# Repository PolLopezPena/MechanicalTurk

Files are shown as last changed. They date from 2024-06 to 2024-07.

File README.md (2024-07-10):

# Mechanical-Turk

## Table of Contents
- [What is it?](#What-is-it?)
- [Requirements](#Requirements)
- [Documentation](#Documentation)
- [Install](#Install)
- [Hardware](#Hardware)
  - [Chess](#Chess)
  - [Face](#Face)
- [Schematic](#Schematic)
- [Software](#Software)
- [3D Components](#3D-Components)
  - [Components List](#Components-List)
  - [How to Use the 3D Files](#How-to-Use-the-3D-Files)
  - [Folder Structure](#Folder-Structure)
- [Authors](#Authors)

## What is it?
The project involves creating an automated chess system inspired by the legendary "Mechanical Turk". This system allows a human user to play chess against a machine, which not only calculates and executes moves on the board but also interacts emotionally through a robotic face. The objective of the project is to combine advanced computer vision, robotics, and programming techniques to offer a unique and interactive gameplay experience.

[Video Chess](https://youtu.be/1_45zRi992Q)

[Video Face](https://www.youtube.com/shorts/0_kBC2aJgIs?feature=share)

## Requirements
**Chess**

 - pip install chess
 
 - pip install stockfish
 
 - pip install time
 
 - pip install RPi.GPIO

 **Face**
 
 - Wire

 - Adafruit_PWMServoDriver

 - SoftwareSerial

 - Adafruit_GFX

 - Adafruit_NeoMatrix

## Documentation

**Project Components**

The project consists of several key components that work together to create a cohesive and smooth experience:

**1. Interactive Chessboard**

*  **Board**: A standard chessboard with magnetic pieces.

*  **Camera**: A camera mounted above the board or into the robotic face to capture images and detect piece movements.

**2. Computer Vision System** 

*  **Piece Detection**: Uses computer vision techniques to recognize and track the pieces on the board.

*  **Movement Recognition**: Detects and records the user's moves by comparing the current state of the board with a reference image.

**3. Piece Movement Mechanism**

*  **Axis System**: X-Y axes equipped with stepper motors that control an electromagnet to move the pieces on the board.

*  **Electromagnet**: Placed under the board, this device lifts and moves the pieces to the desired position.

**4. Chess Control Software**

*  **Chess Engine**: Uses Stockfish, one of the most advanced chess engines, to calculate the machine's moves.

*  **Control Interface**: A Python program that coordinates communication between the chess engine, the vision system, and the motor controller.

**5. Interactive Robotic Face**

*  **Eyes, Brows and Mouth**: Displays different facial expressions in response to the state of the game.

*  **Gestures and Expressions**: Programmed gestures and facial expressions to reflect emotions like happiness, surprise, or frustration, depending on the game's progress.

## Install
To set up Mechanical Turk, follow these steps:

1. Clone the repository to your local machine. $git clone https://github.com/PolLopezPena/MechanicalTurk.git
2. Install the required libraries (check requirements).
3. Execute main Python script.

## Hardware
- ### Chess
| Component | Image | Link |
|---|-----|---|
|**5V stepper motor :**| motor-28byj-48-paso-a-paso-de-5v| https://goo.su/S9cJCD |
|**ULN2003-Stepper Motor Driver Board:**| | https://goo.su/S9cJCD |
|**OcioDual Relay Module 5V 10A:**| 51sQx-WGVOL | https://goo.su/Mz3IfKR |
|**Electromagnet 12V:**|s-l1600 | https://goo.su/75PAyq |
|**Raspberry Pi 3B:**|91zSu44+34L _AC_UF894,1000_QL80_ | https://goo.su/UA1p |
|**Raspberry Pi Camera v2:**|6169R+wUp8L | https://goo.su/2GHD9UQ |
|**ATX 500W Power Supply:**|s-l600 | https://acortar.link/dsBHzn |
|**456 Point Breadboard:**|Breadboard_456P_Vellemans_1-600x600|https://acortar.link/TY06Ol |

- ### Face
| Component | Image | Link |
|---|-----|---|
|**Arduino Nano:**| 73b102980_arduino-nano-r3_x | https://n9.cl/pvt57b|
|**PCA9685 Controller:**| 51kshHMO+YL _AC_ | https://acortar.link/6Guztp
|**4x Micro servo 9G:**| 61uoCSp26qL | https://n9.cl/h44zv|
|**Arduino Uno:**|  | https://n9.cl/hab0d|
|**Neopixel Neomatrix 8x32** | PPADA2294_Neopixel_RGB_LED_MATRIX_FLEXIBLE_main3__44844|https://acortar.link/TBNjKt|

## Schematic
- ### Chess
Chess_sketch
- ### Face
Cabeza_sketch

## Software
### Computer Vision Software
On /Computer_Vision there is the file used to detect the different pieces and the board. The code detects the chessboard and the type of the pieces (Green or Red ones), marking each with a different colour. From the detection, the code also returns the coordinates of where each piece is.

This section lists the 3D components used in the project along with their descriptions, dimensions, and links to the corresponding 3D files.

**IMPORTANT:** In order to use the code you must download [yolov5](https://github.com/ultralytics/yolov5) and place it in a /models sub repository inside the projects repository and place the images desired to be detected inside a /image repository. As seen in lines 111 and 113 in the code.



### Face Software
softwarecara

### Chess Software
ChessSoftware

## 3D Components
### Components List
**1. Rail (2 pieces)**

*  **Description**: Rails for moving the X-Y axes.
*  **Dimensions**:
     * Length: 39.5 cm
       
     * Width: 4 cm
       
     * Height: 3 cm
       
*  **File**: rail.stl

**2. Small Support (2 pieces)**

*  **Description**: First support for mounting one rail on top of another; second support for mounting the electromagnet on the upper rail.
*  **Dimensions**:
     *  Length: 6 cm

     *  Width: 5 cm

     *  Height: 3.65 cm
       
*  **File**: small_support.stl

**3. Wheel Support (2 pieces)**

*  **Description**: Provides stability to the upper rail to prevent oscillation during movement.
*  **Dimensions**:
     *  Length: 1.4 cm
       
     *  Width: 4.2 cm
       
     *  Height: 3.5 cm
       
*  **File**: wheel_support.stl

**4. Motor Support (2 pieces)**

*  **Description**: Holds the motor that drives the belt.
*  **Dimensions**:
     *  Length: 6.5 cm
       
     *  Width: 5 cm
       
     *  Height: 2 cm
       
*  **File**: motor_support.stl

**5. Belt Support (2 pieces)**

*  **Description**: Provides extra support for the belt at the end of the rail.
*  **Dimensions**:
     *  Length: 4 cm
       
     *  Width: 5 cm
       
     *  Height: 2 cm
       
*  **File**: belt_support.stl

**6. Chessboard**

*  **Description**: The chessboard where the game is played.
*  **Dimensions**:
     *  Length: 47.5 cm
       
     *  Width: 47.5 cm
       
     *  Height: 10 cm
       
*  **File**: chessboard.stl

### How to Use the 3D Files
*  **Download**: Click on the file names above to download the STL files.
*  **Print**: Use a 3D printer to print the components. Ensure that your printer settings match the requirements of each component.

### Folder Structure
*  **3D Files Folder**: All 3D files are stored in the **`/3D_files`** directory of this repository.
* **`/3D_files`**
    *  **`rail.stl`**
      
    *  **`small_support.stl`**
      
    *  **`wheel_support.stl`**
      
    *  **`motor_support.stl`**
      
    *  **`belt_support.stl`**
      
    *  **`chessboard.stl`**

## Authors
* Pol López Peña
* Jhonatan Alejandro Quisbert Tarqui
* Pol González Casals

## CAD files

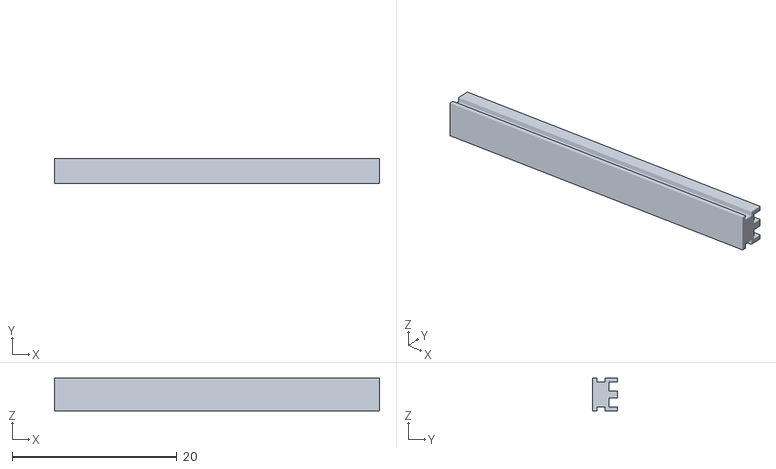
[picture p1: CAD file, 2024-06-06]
3D_files/rail.stl
39.5 x 3.00 x 4.00

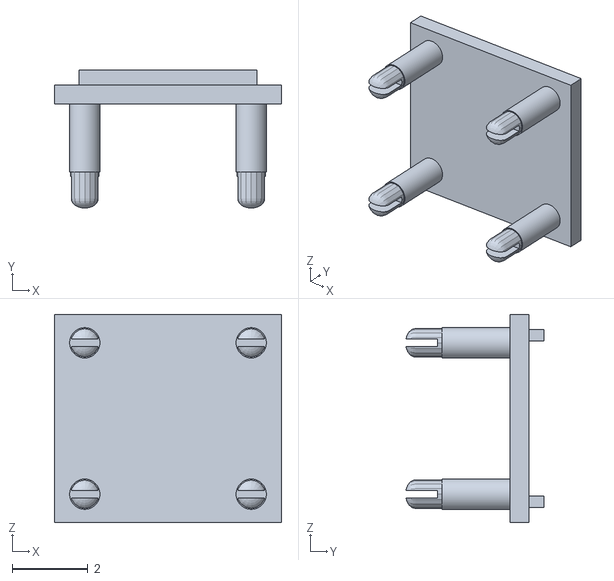
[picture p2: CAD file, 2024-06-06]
3D_files/small_support.stl
6.00 x 3.65 x 5.50

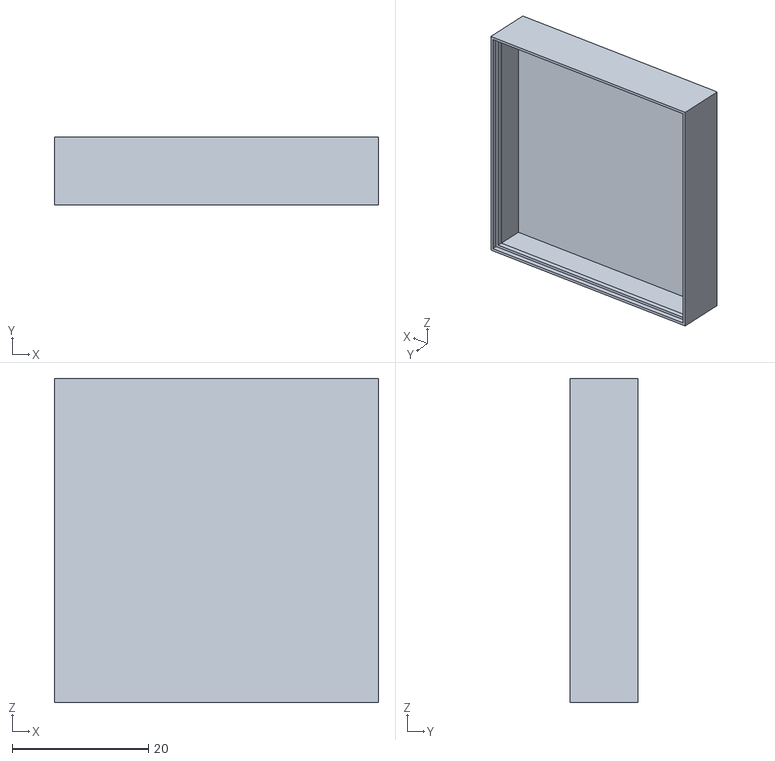
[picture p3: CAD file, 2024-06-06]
3D_files/chessboard.stl
47.5 x 10.0 x 47.5

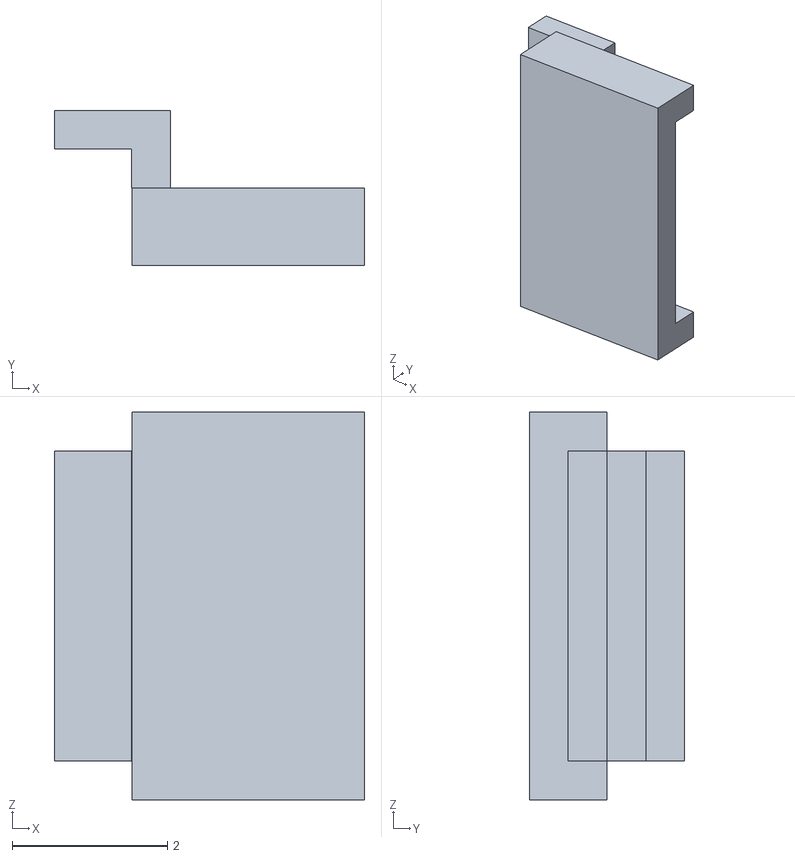
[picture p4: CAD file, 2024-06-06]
3D_files/belt_support.stl
4.00 x 2.00 x 5.00

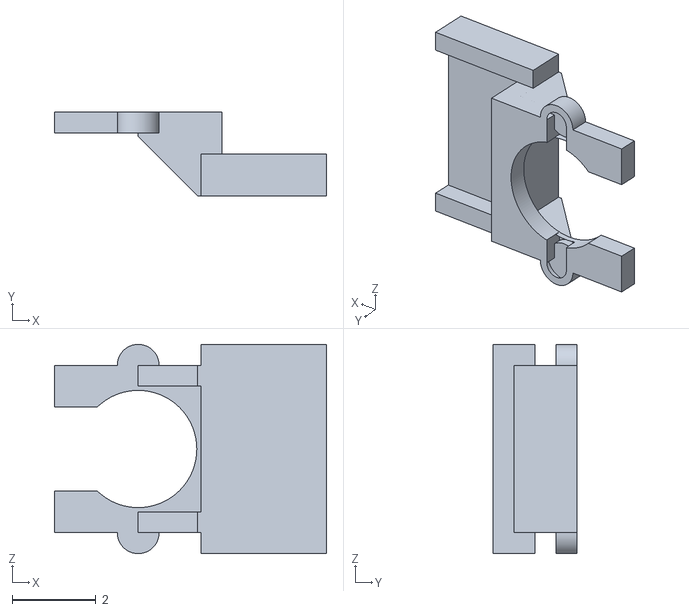
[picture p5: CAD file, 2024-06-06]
3D_files/motor_support.stl
6.50 x 2.00 x 5.00

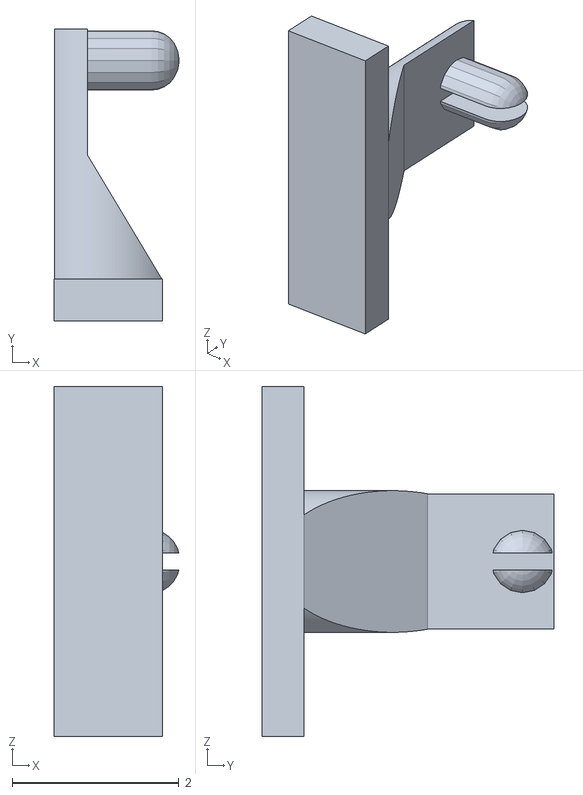
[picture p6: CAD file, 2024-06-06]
3D_files/wheel_support.stl
1.50 x 3.50 x 4.20

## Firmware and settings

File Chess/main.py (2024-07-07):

# This is a sample Python script.
import chess
from stockfish import  Stockfish
import time
import RPi.GPIO as GPIO
# Press Mayús+F10 to execute it or replace it with your code.
# Press Double Shift to search everywhere for classes, files, tool windows, actions, and settings.

# Press the green button in the gutter to run the script.

def init():
        GPIO.setmode(GPIO.BCM)
        magnet = 21
        StepPins = [24, 25, 8, 7]
        StepPins2 = [17, 18, 27, 22]
        for pin in StepPins2:
                print("SetUp Pins1")
                GPIO.setup(pin, GPIO.OUT)
                GPIO.output(pin, False)
        for pin in StepPins:
                print("SetUp Pins2")
                GPIO.setup(pin, GPIO.OUT)
                GPIO.output(pin, False)
        GPIO.setup(magnet, GPIO.OUT)
        return StepPins, StepPins2, magnet
def moveToCoordinate(movement):
        mapping = {'a':1, 'b':2, 'c':3, 'd':4, 'e':5, 'f':6, 'g':7, 'h':8}
        row = mapping[movement[0]]
        col = int(movement[1])
        return row, col
waitTime = 0.002
#Normal-step
# Define simple sequence
StepCount1 = 4
Seq1 = []
Seq1 = [i for i in range(0, StepCount1)]
Seq1[0] = [1, 0, 0, 0]
Seq1[1] = [0, 1, 0, 0]
Seq1[2] = [0, 0, 1, 0]
Seq1[3] = [0, 0, 0, 1]
# Define advanced half-step sequence
StepCount2 = 8
Seq2 = []
Seq2 = [i for i in range(0, StepCount2)]
Seq2[0] = [1, 0, 0, 0]
Seq2[1] = [1, 1, 0, 0]
Seq2[2] = [0, 1, 0, 0]
Seq2[3] = [0, 1, 1, 0]
Seq2[4] = [0, 0, 1, 0]
Seq2[5] = [0, 0, 1, 1]
Seq2[6] = [0, 0, 0, 1]
Seq2[7] = [1, 0, 0, 1]

Seq = Seq2
StepCount = StepCount2

x1 = 0
y1 = 0
x2 = 8
y2 = 8

stepsPerSquare = 2200

def steps(number, pins):
    print(pins)
    StepCounter = 0
    if number < 0:
        sign = -1
    else:
        sign = 1
    nb = abs(number)*2  # Half-step
    for i in range(nb):
        for pin in range(4):
            xpin = pins[pin]
            if Seq[StepCounter][pin] != 0:
                GPIO.output(xpin, True)
            else:
                GPIO.output(xpin, False)
        StepCounter += sign

        if StepCounter == StepCount:
            StepCounter = 0
        if StepCounter < 0:
            StepCounter = StepCount - 1
        time.sleep(waitTime)

def moveController(xSteps, ySteps):
        hasRun = False
        while not hasRun:
                steps(-stepsPerSquare*xSteps, StepPins2)
                time.sleep(1)
                steps(stepsPerSquare*ySteps, StepPins)
                time.sleep(1)
                hasRun = True
        print("Stop Motos")
        for pin in StepPins:
                GPIO.output(pin, False)
        for pin in StepPins2:
                GPIO.output(pin, False)

def moveDiagonal(way):
        stepC = 0
        stepCounter1 = 0
        while stepC < int(stepsPerSquare):
                for pin in range(4):
                        xpin1 = StepPins[pin]
                        if Seq[stepCounter1][pin] != 0:
                                GPIO.output(xpin1, True)
                        else:
                                GPIO.output(xpin1, False)
                        xpin2 = StepPins2[pin]
                        if Seq[stepCounter1][pin] != 0:
                                GPIO.output(xpin2, True)
                        else:
                                GPIO.output(xpin2, False)
                stepCounter1 += way
                if StepCounter1 == StepCount:
                        StepCounter = 0
                if StepCounter1 < 0:
                        StepCounter1 = StepCount - 1
                time.sleep(waitTime)
                stepC +=1
        print("Stop Motos")
        for pin in StepPins:
                GPIO.output(pin, False)
        for pin in StepPins2:
                GPIO.output(pin, False)

#Movement Pieces
def bishopMovement(wayX, wayY, xsteps, ysteps):
        stepC = 0
        stepCounterX = 0
        stepCounterY = 0
        while stepC < int(stepsPerSquare*2):
                for pin in range(4):
                        xpin1 = StepPins[pin]
                        if Seq[stepCounterY][pin] != 0:
                                GPIO.output(xpin1, True)
                        else:
                                GPIO.output(xpin1, False)
                        xpin2 = StepPins2[pin]
                        if Seq[stepCounterX][pin] != 0:
                                GPIO.output(xpin2, True)
                        else:
                                GPIO.output(xpin2, False)
                stepCounterX += wayX
                stepCounterY += wayY
                if stepCounterX == StepCount:
                        stepCounterX = 0
                if stepCounterX < 0:
                        stepCounterX = StepCount - 1
                if stepCounterY == StepCount:
                        stepCounterY = 0
                if stepCounterY < 0:
                        stepCounterY = StepCount - 1
                time.sleep(waitTime)
                stepC +=1
                
        print("Stop Motos")
        for pin in StepPins:
                GPIO.output(pin, False)
        for pin in StepPins2:
                GPIO.output(pin, False)
def horseMovement(xsteps, ysteps):
        moveDiagonal(1)
        time.sleep(2)
        moveController(xsteps, ysteps)
        time.sleep(2)
        moveDiagonal(-1)
def rookMovement(xsteps, ysteps):
        hasRun = False
        if xsteps != 0:
               steps1 = xsteps 
        else:
                steps1 = ysteps
        while not hasRun:
                steps(-stepsPerSquare*steps1, StepPins2)
                time.sleep(1)
                hasRun = True
        print("Stop Motos")
        for pin in StepPins:
                GPIO.output(pin, False)
        for pin in StepPins2:
                GPIO.output(pin, False)
def queenMovement(xsteps, ysteps):
        if xsteps == ysteps:
                if xsteps < 0:
                        wayX = -1
                else:
                        wayX = 1
                if ysteps < 0:
                        wayY = -1
                else:
                        wayY = 1
                for step in range(xsteps):
                        bishopMovement(wayX, wayY, xsteps, ysteps)
        else:
                rookMovement(xsteps, ysteps)
def pawnMovement(xsteps, ysteps):
        if xsteps == 0:
                hasRun = False
                while not hasRun:
                        steps(-stepsPerSquare*ysteps, StepPins)
                        time.sleep(1)
                        hasRun = True
                print("Stop Motos")
                for pin in StepPins:
                        GPIO.output(pin, False)
                for pin in StepPins2:
                        GPIO.output(pin, False)
        else:
                if xsteps < 0:
                        wayX = -1
                else:
                        wayX = 1
                if ysteps < 0:
                        wayY = -1
                else:
                        wayY = 1
                bishopMovement(wayX, wayY, xsteps, ysteps)
                
def movementPieces(typeM, xsteps, ysteps):
        if typeM == 'R':
                rookMovement(xsteps, ysteps)
        elif typeM == 'N':
                horseMovement(xsteps, ysteps)                
        elif typeM == 'B':
                if xsteps < 0:
                        wayX = -1
                else:
                        wayX = 1
                if ysteps < 0:
                        wayY = -1
                else:
                        wayY = 1
                for step in range(xsteps):
                        bishopMovement(wayX, wayY, xsteps, ysteps)
        elif typeM == 'Q':
                queenMovement(xsteps, ysteps)
        elif typeM == 'K':
                queenMovement(xsteps, ysteps)
        elif typeM == 'P':
                pawnMovement()
if __name__ == '__main__':
    StepPins,StepPins2, electroIman = init()
    board = chess.Board()
    time.sleep(2)
    while(board.is_checkmate() == False):
        stockfish1 = Stockfish("/home/alexquper/RLP/Robotica/Stockfish-sf_15/src/stockfish")
        stockfish1.set_depth(10)
        stockfish1.set_skill_level(10)
        move1 = input('Enter the posotion of the piece: ')
        move2 = input('Enter the position of the square: ')
        move = move1 + move2
        board.push_san(move)
        print(board)
        stockfish1.set_fen_position(board.fen())
        moveIA2 = stockfish1.get_best_move()
        piece2 = moveIA2[0] + moveIA2[1]
        square2 = moveIA2[2] + moveIA2[3]
        board.push_san(moveIA2)
        print(board)
        print(moveIA2)
        x1, y1 = moveToCoordinate(piece2)
        print(x1,y1)
        xsteps = x1 - x2
        ysteps = y1 - y2
        moveController(xsteps, ysteps)
        time.sleep(2)
        
        x2, y2 = moveToCoordinate(square2)
        xsteps = x2 - x1
        ysteps = y2 - y1
        #ActivarElectroIman
        GPIO.output(electroIman, GPIO.HIGH)
        time.sleep(2)
        typePiece = board.piece_at(chess.parse_square(square2))
        print(typePiece)
        movementPieces(typePiece, xsteps, ysteps)
        GPIO.output(electroIman, GPIO.LOW)
        print("Stop Iman")
        #ApagamosElectroIman
        time.sleep(2)


# See PyCharm help at https://www.jetbrains.com/help/pycharm/

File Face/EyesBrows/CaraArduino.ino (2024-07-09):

#include <Wire.h>
#include <Adafruit_PWMServoDriver.h>
#include <SoftwareSerial.h>

// Definir pines para SoftwareSerial
SoftwareSerial mySerial(10, 11); // RX, TX

Adafruit_PWMServoDriver servos = Adafruit_PWMServoDriver(0x40);

unsigned int pos0=152; // ancho de pulso en cuentas para pocicion 0°
unsigned int pos180=545; // ancho de pulso en cuentas para la pocicion 180°
char dato;

void setup() {
  // put your setup code here, to run once:
  servos.begin();  
  servos.setPWMFreq(60);

  Serial.begin(9600);
  mySerial.begin(9600);
}

void loop() {
  // put your main code here, to run repeatedly:
  if (Serial.available() > 0) {
    // Lee el dato del puerto serial
    dato = Serial.read();

    mySerial.write(dato);

    // Acciones
    switch (dato) {
      case '1':
        // ENFADADO
        servos.setPWM(8,0,pos180);
        servos.setPWM(0,0,pos0);
        servos.setPWM(4,0,pos0);
        servos.setPWM(12,0,pos0 + 280);
        break;
      case '2':
        // SERIO
        servos.setPWM(8,0,pos0 + 196);
        servos.setPWM(0,0,pos0 + 196);
        servos.setPWM(4,0,pos0);
        servos.setPWM(12,0,pos0 + 280);
        break;
        case '3':
        // PREOCUPADO
        servos.setPWM(8,0,pos0 + 196);
        servos.setPWM(0,0,pos0 + 196);
        servos.setPWM(4,0,pos0 + 650);
        servos.setPWM(12,0,pos0 -60);
        break;
        case '4':
        // ARQUEADO IZQUIERDA
        servos.setPWM(0,0,pos0 + 196);
        servos.setPWM(8,0,pos180);
        servos.setPWM(4,0,pos0);
        servos.setPWM(12,0,pos0 + 280);
        break;
        case '5':
        // ARQUEADO DERECHA
        servos.setPWM(0,0,pos0);
        servos.setPWM(8,0,pos0 + 196);
        servos.setPWM(4,0,pos0);
        servos.setPWM(12,0,pos0 + 280);
        break;
      default:
        // Si se presiona una tecla no reconocida, no hace nada
        break;
    }
  }
}
